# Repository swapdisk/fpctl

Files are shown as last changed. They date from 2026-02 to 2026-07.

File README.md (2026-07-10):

# fpctl: The FlightPath Controller

An ESP32-based physical cockpit designed to navigate the virtual skies of [FlightGear](https://www.flightgear.org/) and spark real-world conversations.

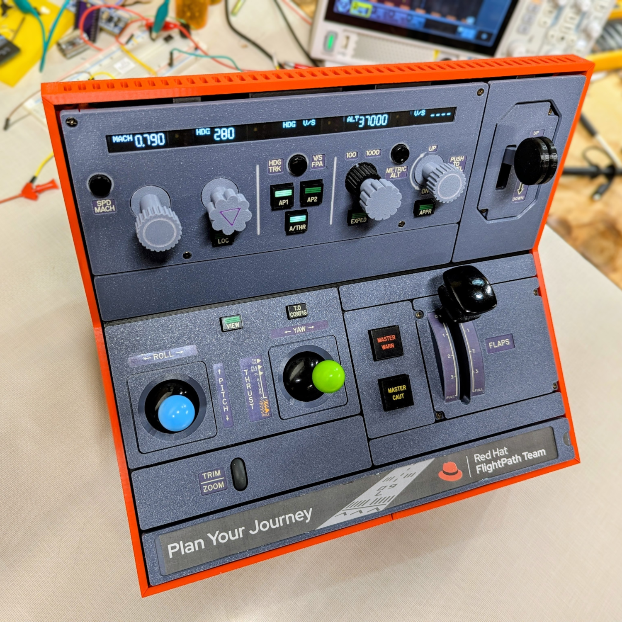
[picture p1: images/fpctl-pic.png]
FlightPath Controller


## About the Project

**fpctl** is a custom-built hardware flight deck interface designed specifically for the FlightPath Team at Red Hat.

Modeled largely after the Airbus A320 Flight Control Unit (FCU) and pedestal, this device serves as an interactive convention exhibit to show off on the expo floor and at happy hour receptions. Its primary purpose is to attract attention and serve as a unique conversation starter, demonstrating how physical hardware can integrate seamlessly with complex software systems, a tangible metaphor for the journeys we help our customers plan and execute.

It bridges the physical and digital worlds, allowing users to get hands-on with a flight simulator using realistic controls and displays, rather than just a keyboard and mouse.

## Features

The controller uses a hybrid approach to interface with the FlightGear simulator, combining low-latency USB HID inputs with bi-directional serial communication for complex data.

* The device appears to the host computer as both a standard USB HID Gamepad for sticks and buttons and a USB Serial device  for data exchange.
* The A320 FCU features dedicated rotary encoder knobs for speed/mach, heading/track, altitude, and vertical speed/FPA.
* Each knobs mechanically implements the push/pull functionality used to switch between manually-selected and FMGC-managed autopilot modes.
* Five distinct OLED screens provide real-time feedback from the simulator, showing current flight parameters like target altitude, heading and speed synced via a custom serial protocol.
* The physical controls include analog joysticks for flight control, joystick view mode for panning and zooming the main simulator canvas, a dedicated flaps lever with detents, a landing gear switch, and various autopilot engagement buttons.
* Visual and audio feedback features include master warning and caution indicators and a built-in speaker for clicks and alert sounds providing immediate sensory feedback.

## How It's Built

At its heart, the controller is powered by an ESP32 microcontroller. To manage the extensive array of inputs and outputs with limited pins, the project employs several engineering tricks:

* Multiplexing is used to update the five SSD1306 OLED displays which share the same I2C address. A [PCA9548A I2C switch](https://www.nxp.com/docs/en/data-sheet/PCA9548A.pdf) is used to rapidly switch between them, allowing individual updates.
* Input multiplexing is achieved using resistor ladders, allowing the dozens of buttons to be read using only three analog input pins, significantly reducing the total GPIO count required.
* Five high-precision rotary encoders manage the autopilot knobs with push/pull capability physically implemented with a custom 3D-printed "[floating hinge](FLIPPIES.md)" mechanism.
* Analog inputs use potentiometers handle the joysticks and the flaps lever position.

## Software Architecture

The ESP32 firmware is written in C++ using the Arduino framework. The main loop runs at around 30K iterations per second on an [Espressif ESP32-S3-DevKitC](https://docs.espressif.com/projects/esp-dev-kits/en/latest/esp32s3/esp-dev-kits-en-master-esp32s3.pdf), acting as a highly efficient manager of several distinct subsystems:

* Reads analog sticks and resistor ladder buttons, sending standard USB HID Gamepad events to the host PC.
* High-frequency polling of rotary encoders ensures precise input tracking without missed clicks.
* Bi-Directional serial sync:
  * Input: The ESP32 parses a custom, pipe-separated (`|`) data stream arriving from FlightGear via serial. This data drives the OLED displays and LED indicators, ensuring the hardware always matches the simulation state.
  * Output: Functions like changing autopilot targets and controlling simulator view/zoom are sent to FlightGear as nasal script commands to be executed by the simulator.

## What's Here

This repo contains all the files used to make this project, but no effort has been taken to make this something anybody can recreate exactly. What I made was very much a prototype engineered piece by piece without any final design plan. Here's a look inside:

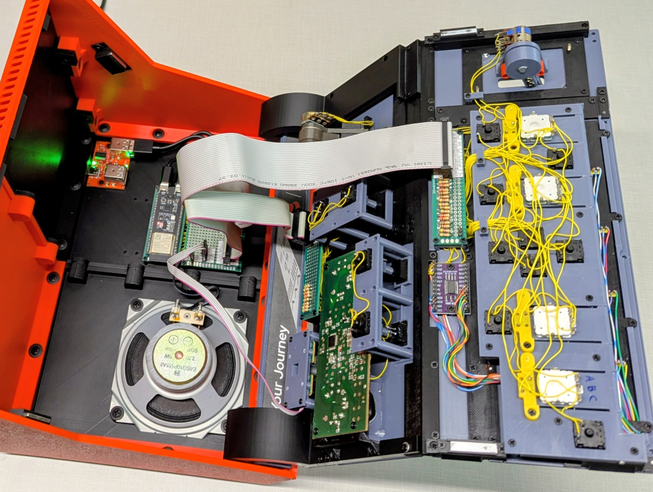
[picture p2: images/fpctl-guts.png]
Project Guts


There is no bill of materials listing everything you need to order up on Digikey. Many of the components came out of my parts bins or were scrapped from other projects. So it's in that vein what's in this repo is offered. It's not a recipe to recreate exactly what I built, but rather a collection of code and ideas you can draw on to create your own thing.

* The OpenSCAD files for all the 3D printed parts are under the [`3d`](./3d/) directory. I built this one panel at a time using a building block approach. With better planning and more discipline, it could have probably been done with half as many parts. Apologies in advance for the cryptic comments and plethora of magic numbers. Use what you can as you see fit.

* The ESP32 firmware is in [`src/fpctl.ino`](./src/fpctl.ino). Unlike the messy 3D models mentioned above, this is nice clean C++ code and commented pretty well.

Interfaces and modifications to FlightGear are implemented by the following files which must be copied as explained below.

* [`fgfs/Protocol/fpctl.xml`](./fgfs/Protocol/fpctl.xml) defines the serial protocol that sends data from FlightGear to the controller. This file needs to be copied to the `$FG_ROOT/Protocol` directory on the host. See the comments at the top of the file for the example option that needs to be given on the `fgfs` command line or configured in your `.fgfsrc` file.
* [`fgfs/Input/Joysticks/js0.xml`](./fgfs/Input/Joysticks/js0.xml) defines the input bindings for the USB HID Gamepad axes and buttons send from the controller. This file needs to be copied to your `$HOME/.fgfs/Input/Joysticks/` directory.
* [`bin/naselx.sh`](./bin/nasalx.sh) is a simple shell script that reads nasal script commands sent from the controller and forwards them to be executed by FlightGear. This script needs to be run in the background and FlightGear needs to be run with the following options on the `fgfs` command line or configured in your `.fgfsrc` file:<br>
`--telnet=5401`<br>
`--allow-nasal-from-sockets`
* [`fgfs/Liveries/FP-fuselage.png`](./fgfs/Liveries/FP-fuselage.png) is a 4k fuselage image I made for the FlightPath team. Copy this over the fuselage image file of the A320-family plane you are flying (e.g., `DLH-fuselage.png`) to see this rendered in the simulator.

## Credits

This project was made possible by the inspiration and contributions of many. Thank you!

* Josh Davidson, et al, for the very advanced [Airbus A320 Family](https://github.com/legoboyvdlp/A320-family) simulation for FlightGear
* Matthias Hertel's top notch [RotaryEncoder Arduino Library](https://github.com/mathertel/RotaryEncoder)
* Limor Fried and Adafruit Industries for their [Adafruit_SSD1306](https://github.com/adafruit/Adafruit_SSD1306/) OLED display library
* Chris Stone at Ignorant of Things for clearly explaining the right way to do [resistor ladders](https://ignorantofthings.com/pushing-adc-limits-with-the-perfect-multi-button-input-resistor-ladder/)
* Darren Embry's beautifully crafted [Routed Gothic Font](https://github.com/dse/routed-gothic)
* Red Hat for sharing their commercial-grade [typefaces](https://github.com/RedHatOfficial/RedHatFont) with open source licensing

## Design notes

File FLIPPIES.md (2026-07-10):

# FCU knobs push-pull implementation

Here a quick explanation of how we made the push-pull function for the FCU target knobs.

Each of the rotary encoders is mounted on floating hinge element of the base plate behind the FCU panel. These are referred to as "flippies" in the source code of [`fcu-p2.scad`](https://github.com/swapdisk/fpctl/blob/main/3d/fcu-p2.scad). For the hinge pin, we just used a piece 1.75 mm PLA filament. Sandwiched around each flippy are a pair of [`pushpull-fit.scad`](https://github.com/swapdisk/fpctl/blob/main/3d/pushpull-fit.scad) parts, one on top and one below. Each one holds a 6 mm tactile button switch in such a way to limit the movement of the encoder mounted to the flippy while activating either the top or bottom switch when the encoder knob is pushed and pulled.

The exploded view drawing and photo below should help you visualize how it's put together.

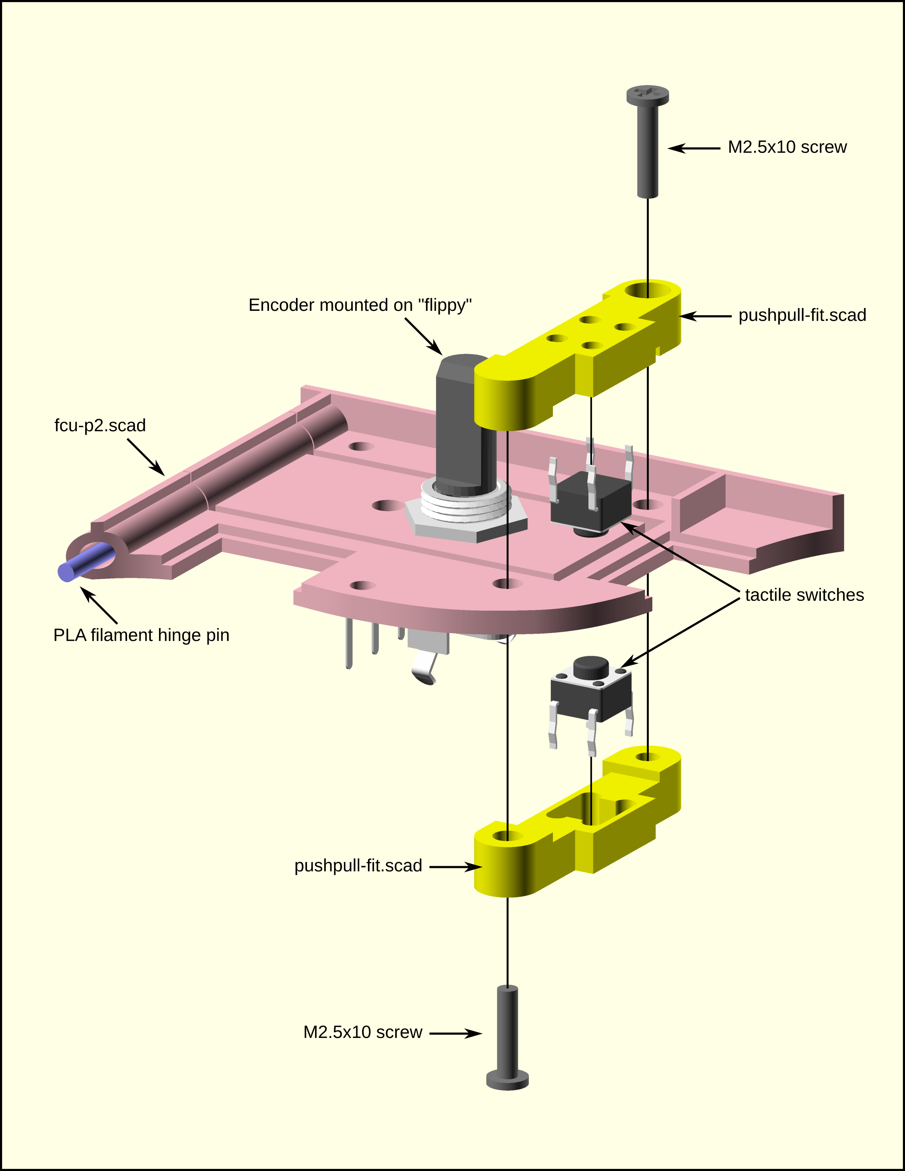
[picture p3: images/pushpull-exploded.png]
Exploded view of floating hinge mechanism


Photo of the assembled parts

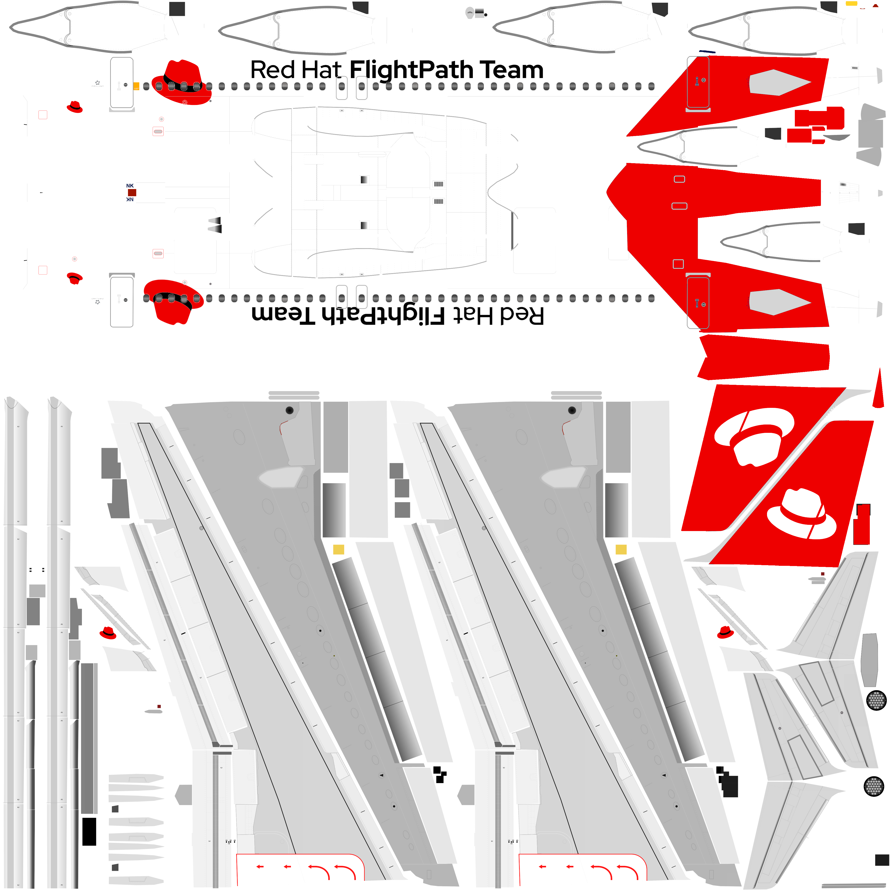
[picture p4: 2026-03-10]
fgfs/Liveries/FP-fuselage.png

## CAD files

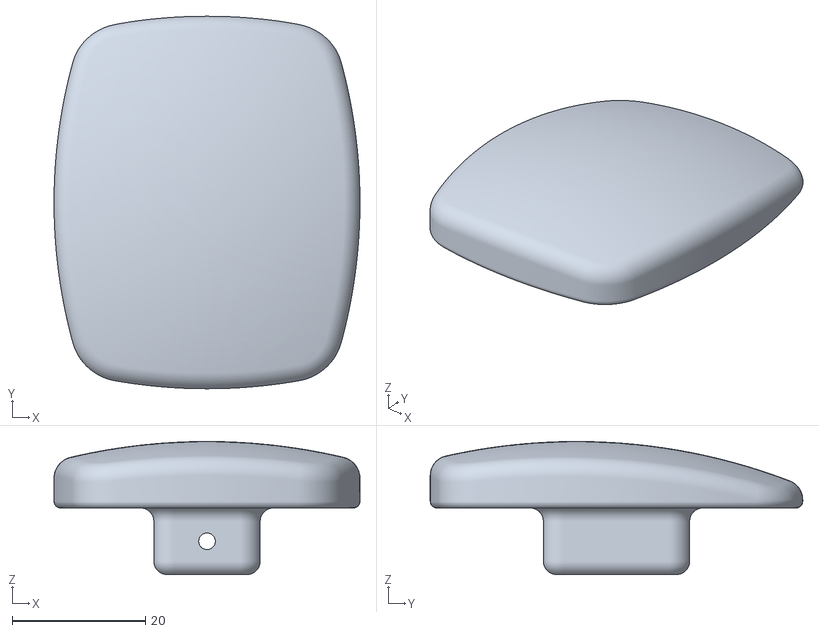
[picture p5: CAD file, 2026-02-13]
3d/flaps-assembly-ma60-21-top-knob.stl
46.0 x 56.0 x 20.0

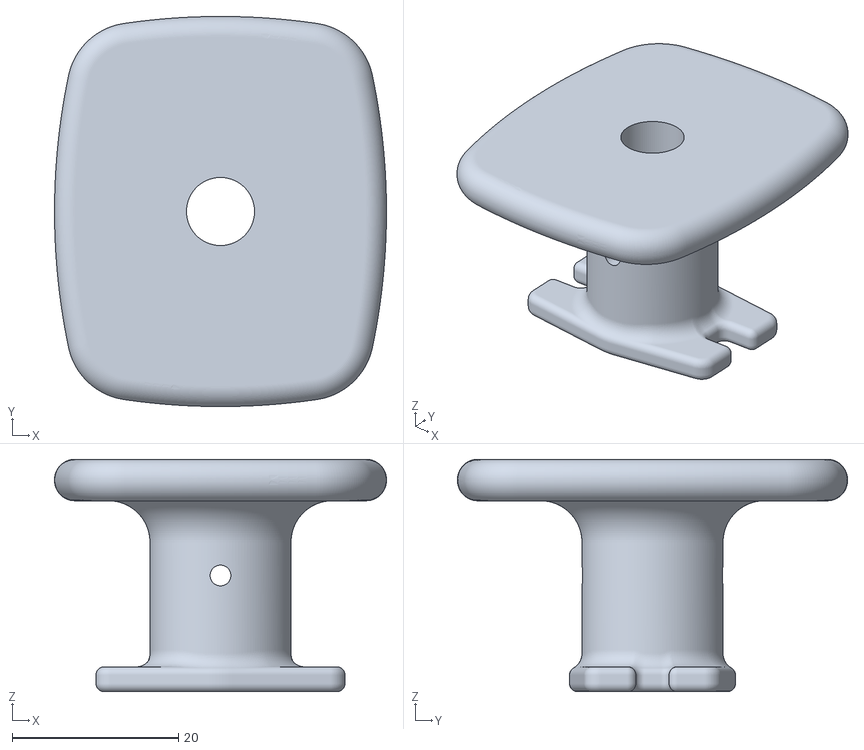
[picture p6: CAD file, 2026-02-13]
3d/flaps-assembly-ma60-20-pull-knob.stl
40.0 x 47.0 x 28.0

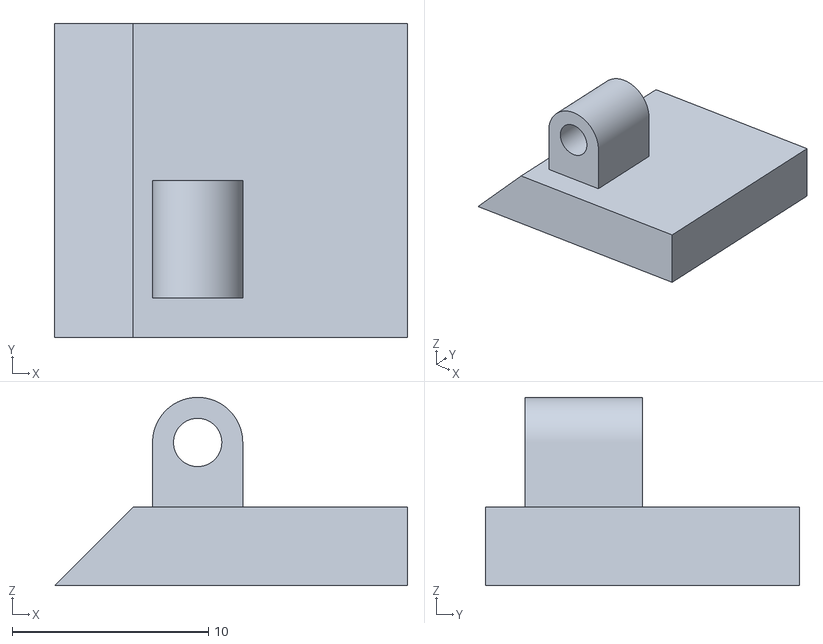
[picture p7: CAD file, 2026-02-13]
3d/case-corner-mini.stl
18.0 x 16.0 x 9.60

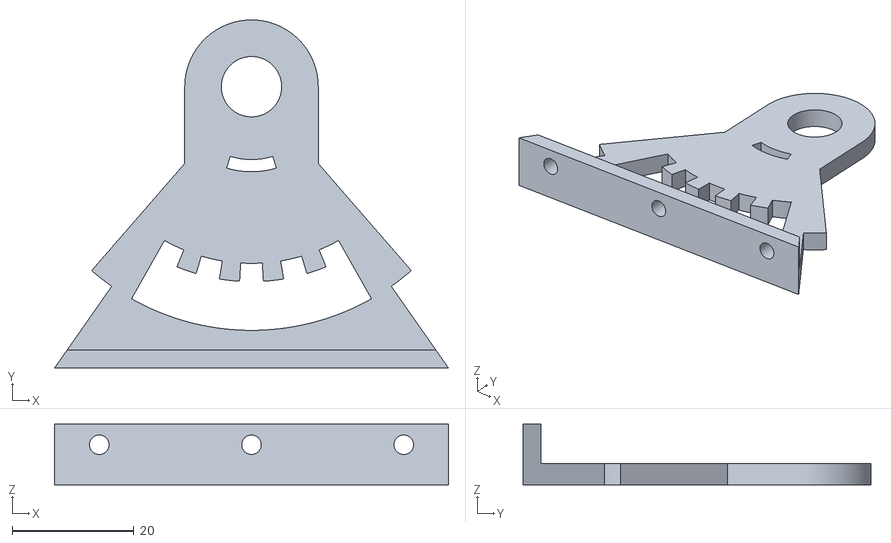
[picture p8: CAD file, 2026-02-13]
3d/flaps-control-lower.stl
64.7 x 57.1 x 10.0

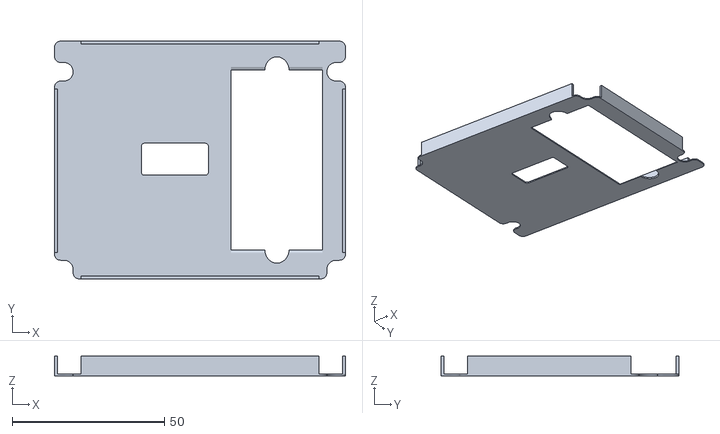
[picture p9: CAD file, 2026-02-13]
3d/flaps-control-face.stl
95.5 x 78.0 x 6.40

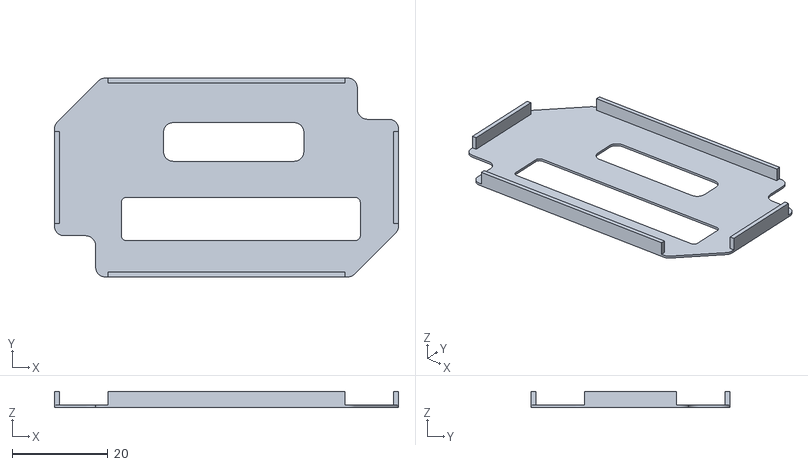
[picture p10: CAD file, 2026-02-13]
3d/gear-control-panel-face.stl
72.0 x 41.6 x 3.40

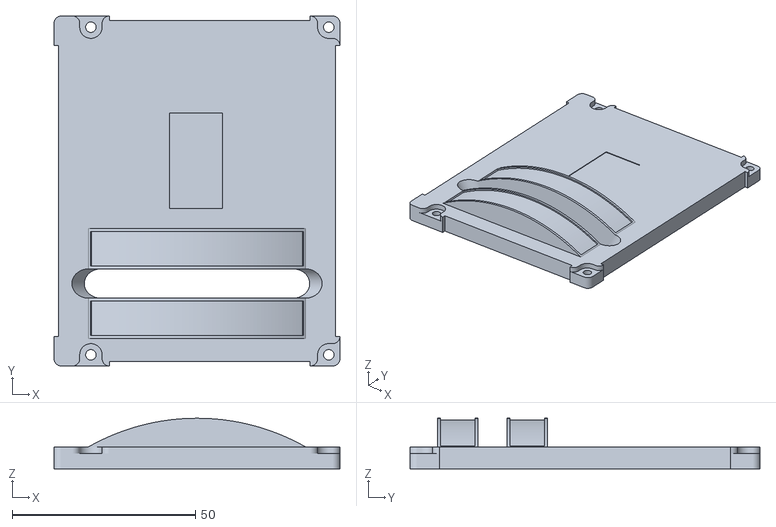
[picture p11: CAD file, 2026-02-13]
3d/flaps-control-panel.stl
78.0 x 95.5 x 13.8

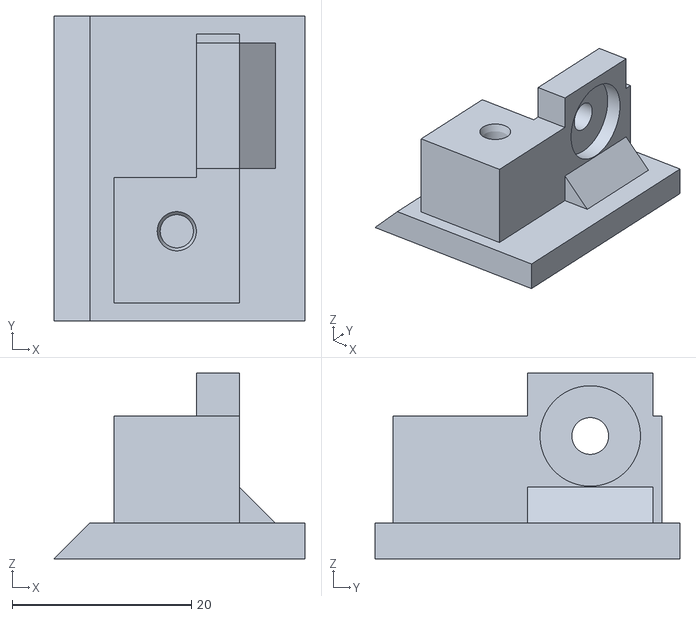
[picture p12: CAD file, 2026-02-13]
3d/case-corner-test.stl
28.0 x 34.0 x 20.7

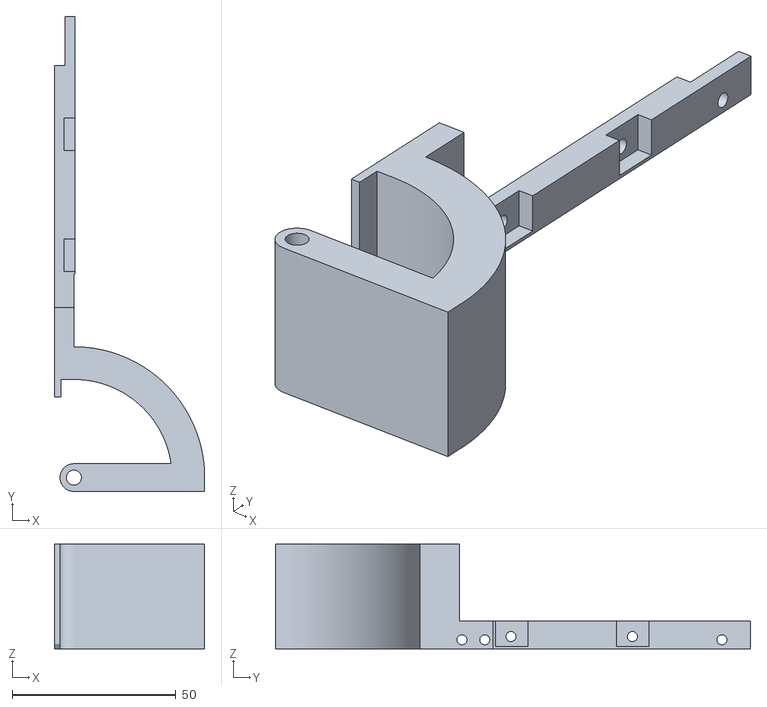
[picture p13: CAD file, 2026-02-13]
3d/hinge-left.stl
46.0 x 145.2 x 32.0

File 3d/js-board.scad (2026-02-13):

$fn=360;
eps=0.01;

// Board dims
pcb_x=115.10;
pcb_y=52.50;
pcb_thick=1.62;
pcb_hole_rad=2.64/2;
pcb_holes=[ [3.96, 4.08],
            [3.96, 41.22],
            [110.97, 4.08],
            [110.97, 41.22]];
            
// Joystick control dims
jsc_x=15.75;
jsc_y=15.75;
jsc_z=12.22;
jsc_pos=[ [9.40, 13.45],
          [89.56, 13.45]];
          
// Stick dims
jss_x=1.86;
jss_y=1.18;
jss_z=19.62;

// Dome position
dome_high=10.75;

// Debug show board, etc.
translate([0, 0, -pcb_thick]) difference() {
    union() {
        // base pcb
        color("powderblue") cube([pcb_x, pcb_y, pcb_thick]);
        // Joysticks
        color("silver") for (j=jsc_pos) {
            translate([j[0], j[1], pcb_thick])
                cube([jsc_x, jsc_y, jsc_z]);
            translate([j[0]+jsc_x/2-jss_x/2, j[1]+jsc_y/2-jss_y/2, pcb_thick])
                cube([jss_x, jss_y, jss_z]);
        }
        // Domes
        color("grey") for (j=jsc_pos) {
            translate([j[0]+jsc_x/2, j[1]+jsc_y/2, pcb_thick+dome_high]) {
                include <ex-sphere.scad>;
            }
        }
    }
    for (h=pcb_holes) {
        translate([h[0], h[1], -eps]) cylinder(99, pcb_hole_rad, pcb_hole_rad);
    }
}

// Shorten brackets to go under jointer by this amount
shorter=2.3;

// Bracket poly points
bpp=[[0, shorter],
     [0, 5],
     [5.5, 10.5],
     [5.5, 18.82],
     [17.5-7.5/2, 18.82],
     [17.5-7.5/2, 18.82-2.10],
     [9.58+2.10, 18.82-2.10],
     [7.5, 12.12],
     [7.5, shorter]];
pcb_screw_rad=2.46/2;
pcb_screw_deep=2.7;
pan_hole_rad=3.06/2;
pan_head_rad=4.60/2;
pan_deep=5.5;

//            [3.96, 41.22],
//            [110.97, 4.08],
//            [110.97, 41.22]];
// right bracket
translate([110.97+3.96, 0.21+41.22+3.88, 0]) rotate([0, 0, 180]) difference() {
    translate([-9.75, 0.21, 18.82]) {
        // body
        rotate([90, 180, 180]) linear_extrude(7.5) polygon(bpp);
        translate([0, 41.22-4.08, 0]) rotate([90, 180, 180]) {
            linear_extrude(7.5) polygon(bpp);
        }
        translate([17.5-7.5/2, 7.5/2, -18.82]) rotate([0, 0, 0]) cylinder(2.10, 7.5/2, 7.5/2);
        translate([17.5-7.5/2, 41.22-4.08+7.5/2, -18.82]) rotate([0, 0, 0]) cylinder(2.10, 7.5/2, 7.5/2);
        translate([5.5, 0, -18.82]) cube([2, 41.22, 18.82-8.5]);
    }
    // board screw holes
    for (h=[[3.96, 4.08], [3.96, 41.22]]) {
        translate([h[0], h[1], -eps]) cylinder(pcb_screw_deep, pcb_screw_rad, pcb_screw_rad);
    }
    // panel screw holes
    for (h=[[-7, 4.08], [-7, 41.22]]) {
        translate([h[0], h[1], -eps]) cylinder(99, pan_hole_rad, pan_hole_rad);
        translate([h[0], h[1], -eps]) cylinder(18.82-pan_deep, pan_head_rad, pan_head_rad);
    }
}

// left bracket
difference() {
    translate([-9.75, 0.21, 18.82]) {
        // body
        rotate([90, 180, 180]) linear_extrude(7.5) polygon(bpp);
        translate([0, 41.22-4.08, 0]) rotate([90, 180, 180]) linear_extrude(7.5) polygon(bpp);
        translate([17.5-7.5/2, 7.5/2, -18.82]) rotate([0, 0, 0]) cylinder(2.10, 7.5/2, 7.5/2);
        translate([17.5-7.5/2, 41.22-4.08+7.5/2, -18.82]) rotate([0, 0, 0]) cylinder(2.10, 7.5/2, 7.5/2);
        translate([5.5, 0, -18.82]) cube([2, 41.22, 18.82-8.5]);
    }
    // board screw holes
    for (h=[[3.96, 4.08], [3.96, 41.22]]) {
        translate([h[0], h[1], -eps]) cylinder(pcb_screw_deep, pcb_screw_rad, pcb_screw_rad);
    }
    // panel screw holes
    for (h=[[-7, 4.08], [-7, 41.22]]) {
        translate([h[0], h[1], -eps]) cylinder(99, pan_hole_rad, pan_hole_rad);
        translate([h[0], h[1], -eps]) cylinder(18.82-pan_deep, pan_head_rad, pan_head_rad);
    }
}

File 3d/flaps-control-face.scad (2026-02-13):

$fn=360;
eps=0.01;

// Cover dims
cov_thick=0.50;

// Minifactorize
mf=20;

// Bezel dims
bezel_thick=3;
bezel_corner_rad=3;
bezel_f=1.25;

// Panel dims
panel_thick=3;
panel_margin=6;
panel_f=1.3;
panel_l=7.5;
panel_r=58;

// Flap control dims
arch_rad=80-mf;
total_wide=30;
slot_wide=8;
detent_wide=8;
detent_rad=arch_rad-28;
detent_deep=3;
detent_deg=7;

// Deco mounting corners
dmc_xy=6.10;
dmc_ty=7.00;
sm_rad=2;
lg_rad=dmc_xy/2;
dmc_hole_rad=2.86/2;
gp_base=4.2;
gp_high=arch_rad*panel_f;
gp_wide=panel_l+total_wide+panel_r;

// Potentiometer dims
pot_rad=9.90/2;
pot_reg_wide=2.0;
pot_reg_offset=11.96;

// Label cavity
lc_deep=0.5;
lc_edge=0.8;

// Label
lab_thick=0.20;
lab_rad=1;
lab_mar=3;
lab_corners=[[-36, 45, lab_rad],
            [-36-8.5, 45, lab_rad],
            [-36-8.5, 45+20, lab_rad],
            [-36, 45+20, lab_rad]];

// Attachment
screw_rad=2.46/2;
screw_deep=panel_thick+bezel_thick+2;
el_thick=3;
el_holes_rad=3.20/2;

// Face tabs
s=1.10;
tab_thick=1.0;
ft=[[dmc_xy*2+dmc_ty+sm_rad-gp_high+s/2, 0, gp_high-dmc_xy*2-sm_rad*2-dmc_ty-s, tab_thick],
    [dmc_xy*2+dmc_ty+sm_rad-gp_high+s/2, gp_wide-tab_thick, gp_high-dmc_xy*2-sm_rad*2-dmc_ty-s, tab_thick],
    [dmc_xy-tab_thick, dmc_xy+sm_rad+s/2, tab_thick, gp_wide-sm_rad*2-dmc_xy*2-s],
    [dmc_xy-gp_high, dmc_xy+sm_rad+s/2, tab_thick, gp_wide-sm_rad*2-dmc_xy*2-s]];

// subtractable radius
module sr(deg) {
    rotate([0, 0, deg]) linear_extrude(99) {
        difference() {
            square([sm_rad, sm_rad]);
            intersection() {
                square([sm_rad, sm_rad]);
                translate([sm_rad, sm_rad, 0]) circle(sm_rad);
            }
        }
    }
}

rotate([0, 180, 90]) translate([0, 0, -arch_rad*0.87+panel_thick+bezel_thick]) difference() {
    union() {
        // face tabs
        translate([arch_rad*panel_f/2-dmc_xy,
                       -total_wide-panel_l, 
                       arch_rad*0.87-cov_thick]) {
            for (f=ft) {
                translate([f[0], f[1], -6+0.1]) cube([f[2], f[3], 6]);
            }
        }
    }
}

//projection(cut=true) translate([0, 0, panel_thick+bezel_thick])
rotate([0, 180, 90]) translate([0, 0, -arch_rad*0.87+panel_thick+bezel_thick]) difference() {
    union() {
        // guide base
        rotate([90, -49, 0]) rotate_extrude(angle=82) 
            translate([0, 0, 0]) square([detent_rad+detent_wide, total_wide]);
        
        // panel 
        translate([-arch_rad*panel_f/2,
                   -total_wide-panel_l, 
                   arch_rad*0.87-panel_thick-bezel_thick])
            linear_extrude(bezel_thick+panel_thick) hull() {
                translate([sm_rad, sm_rad, 0]) circle(sm_rad);
                translate([arch_rad*panel_f-sm_rad, sm_rad, 0]) circle(sm_rad);
                translate([arch_rad*panel_f-sm_rad, panel_l+total_wide+panel_r-sm_rad, 0])
                    circle(sm_rad);
                translate([sm_rad, panel_l+total_wide+panel_r-sm_rad, 0]) circle(sm_rad);    
        }
    }

    // Cover only
    translate([-49, -49, arch_rad*0.87-99-cov_thick]) cube([99, 99*2, 99]);
    
    // main control body
    rotate([90, -55, 0]) rotate_extrude(angle=70) square([arch_rad, total_wide]);

    
    // subtract face tabs
//    translate([arch_rad*panel_f/2-dmc_xy,
//                   -total_wide-panel_l, 
//                   arch_rad*0.87-panel_thick-bezel_thick]) {
//        for (f=ft) {
//            translate([f[0], f[1], -eps]) cube([f[2], f[3], 99]);
//        }
//    }

    // subtract deco mounting corners
    // bottom left
    translate([arch_rad*panel_f/2-dmc_xy,
                   -total_wide-panel_l, 
                   arch_rad*0.87-panel_thick-bezel_thick]) {
                   //%cylinder(99, .1, .1);
        translate([0, 0, gp_base]) sr(90);
        translate([dmc_xy, dmc_xy, gp_base]) sr(90);
        translate([0, 0, gp_base]) linear_extrude(9) hull() {
            translate([dmc_xy, dmc_xy-lg_rad, 0]) circle(lg_rad);
            translate([lg_rad, dmc_xy-lg_rad, 0]) circle(lg_rad);
            translate([lg_rad, 0, 0]) circle(lg_rad);
            translate([dmc_xy, 0, 0]) circle(lg_rad);
        }
        translate([dmc_xy-lg_rad, dmc_xy-lg_rad, -eps])
            cylinder(99, dmc_hole_rad, dmc_hole_rad);
    }
    // bottom right
    translate([arch_rad*panel_f/2-dmc_xy,
                   -total_wide-panel_l, 
                   arch_rad*0.87-panel_thick-bezel_thick]) {
        translate([0, panel_l+total_wide+panel_r, gp_base]) sr(180);
        translate([dmc_xy, panel_l+total_wide+panel_r-dmc_xy, gp_base]) sr(180);
        translate([0, panel_l+total_wide+panel_r-dmc_xy/2, gp_base]) linear_extrude(9) hull() {
            translate([dmc_xy, dmc_xy-lg_rad, 0]) circle(lg_rad);
            translate([lg_rad, dmc_xy-lg_rad, 0]) circle(lg_rad);
            translate([lg_rad, 0, 0]) circle(lg_rad);
            translate([dmc_xy, 0, 0]) circle(lg_rad);
        }
        translate([dmc_xy-lg_rad, panel_l+total_wide+panel_r-lg_rad, -eps]) 
            cylinder(99, dmc_hole_rad, dmc_hole_rad);
    }
    // top left
    translate([dmc_ty-arch_rad*panel_f/2,
                   -total_wide-panel_l, 
                   arch_rad*0.87-panel_thick-bezel_thick]) {
        translate([0, 0, gp_base]) sr(90);
        translate([dmc_xy, 0, gp_base]) sr(0);
        translate([0, 0, gp_base]) linear_extrude(9) hull() {
            translate([lg_rad, dmc_xy-lg_rad, 0]) circle(lg_rad);
            translate([lg_rad, 0, 0]) circle(lg_rad);
        }
        translate([lg_rad, dmc_xy-lg_rad, -eps]) 
            cylinder(99, dmc_hole_rad, dmc_hole_rad);
    }
    // top right
    translate([dmc_ty-arch_rad*panel_f/2,
                   -total_wide-panel_l, 
                   arch_rad*0.87-panel_thick-bezel_thick]) {
        translate([0, panel_l+total_wide+panel_r, gp_base]) sr(180);
        translate([dmc_xy, panel_l+total_wide+panel_r, gp_base]) sr(270);
        translate([0, panel_l+total_wide+panel_r-dmc_xy/2, gp_base]) linear_extrude(9) hull() {
            translate([lg_rad, dmc_xy-lg_rad, 0]) circle(lg_rad);
            translate([lg_rad, 0, 0]) circle(lg_rad);
        }
        translate([lg_rad, panel_l+total_wide+panel_r-lg_rad, -eps]) 
            cylinder(99, dmc_hole_rad, dmc_hole_rad);
    }

    translate([0, -total_wide/2+slot_wide/2, 0]) {
        // lever slot
        rotate([90, -60.5, 0]) rotate_extrude(angle=59) square([999, slot_wide]);
        // round ends of slot
        translate([0, -slot_wide/2, 0])
            rotate([-29.5, 0, 90]) cylinder(999, slot_wide/2, slot_wide/2);
        translate([0, -slot_wide/2, 0])
            rotate([29.5, 0, 90]) cylinder(999, slot_wide/2, slot_wide/2);
        // subtract left side
        translate([-arch_rad*panel_f/2, -total_wide+1, -999])
            cube([arch_rad*panel_f, total_wide, 999+arch_rad*0.87-panel_thick-bezel_thick]);
        // subtract right side
        translate([-arch_rad*panel_f/2, 3.5-3+slot_wide/2, -999])
            cube([arch_rad*panel_f, total_wide, 
                999+arch_rad*0.87-panel_thick-bezel_thick-el_thick]);
    }
    // el holes
    for (x = [-arch_rad*bezel_f/3, 0, arch_rad*bezel_f/3]) {
        translate([x, -4.4-3+slot_wide/2, arch_rad*0.87-panel_thick-bezel_thick-el_thick-eps]) 
            cylinder(el_thick+eps+eps, el_holes_rad, el_holes_rad);
    }
    // screw holes
    for (x = [-arch_rad*bezel_f/3, 0, arch_rad*bezel_f/3]) {
        translate([x, -4.4-3+slot_wide/2, arch_rad*0.87-panel_thick-bezel_thick-eps]) 
            cylinder(screw_deep-0.9, screw_rad, screw_rad);
        translate([x, 4.4+3-slot_wide/2-total_wide, arch_rad*0.87-panel_thick-bezel_thick-eps]) 
            cylinder(screw_deep-0.9, screw_rad, screw_rad);
    }

    // label cavities
    rotate([90, -61, 0]) rotate_extrude(angle=58) 
        translate([arch_rad-lc_deep, lc_edge, 0])
            square([999, total_wide/2-slot_wide/2-lc_edge*2]);
    rotate([90, -61, 0]) rotate_extrude(angle=58) 
        translate([arch_rad-lc_deep, lc_edge+total_wide/2+slot_wide/2, 0])
            square([999, total_wide/2-slot_wide/2-lc_edge*2]);

    // subtract label
    translate([arch_rad*panel_f/2,
                   -total_wide-panel_l, 
                   0]) linear_extrude(99) hull() {
        for (i = [0:3]) {
            c=lab_corners[i];
            translate([c[0]+c[2],
                       c[1]+c[2],
                       0]) circle(lab_rad);
        }
    }
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

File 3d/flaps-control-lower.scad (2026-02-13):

eps=0.01;

rotate([90, 0, 0]) difference() {
    union() {
        include<flaps-control.scad>;
    }
    translate([0, 0, -eps]) cylinder(99, 99, 99);
}

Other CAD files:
3d/flaps-control-mockup.scad
3d/alt-units-knob-flange.scad
3d/alt-units-knob-pointer.scad
3d/alt-units-knob-ring.scad
3d/alt-units-proto.scad
3d/blank-panel-a.scad
3d/blank-panel-b-face.scad
3d/blank-panel-b.scad
3d/c2-keymate.scad
3d/case-back-left.scad
3d/case-back-right.scad
3d/case-bottom-left.scad
3d/case-bottom-right.scad
3d/case-bottom.scad
3d/case-corner-mini.scad
3d/case-corner-test.scad
3d/case-esp-adapter.scad
3d/case-front-panel-left.scad
3d/case-front-panel-right.scad
3d/case-side-left-panel.scad
3d/case-side-right-panel.scad
3d/case-top-stop.scad
3d/case-top.scad
3d/cherry-cherry-short.scad
3d/cherry-cherry.scad
3d/cherry-escutcheon.scad
3d/cherry-female.scad
3d/cherry-keycap-fcu0.scad
3d/cherry-keycap-fcu1.scad
3d/cherry-keycap-fcu2.scad
3d/cherry-keymate.scad
3d/cherry-ko.scad
3d/disp-clip.scad
3d/duct-cover-raceway.scad
3d/ex-sphere.scad
3d/fcu-display.scad
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

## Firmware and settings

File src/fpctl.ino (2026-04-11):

/*
  fpctl

  Interface Airbus A320 cockpit to FlightGear flight sim using ESP32.

  The controller appears on the USB bus as both a HID gamepad device and 
  a serial port. Most of the inputs to FlightGear are handled as joystick 
  axes and buttons. The other inputs are implemented by sending nasal 
  commands over the serial port. We also read from the serial port to get 
  outputs from a custom FlightGear protocol to update the FCU displays 
  and indicators.

  https://github.com/swapdisk/fpctl
  
  (c) 2026 Bob Mader
  MIT License

*/

// USB and Gamepad libraries
#include "USB.h"
#include "USBHIDGamepad.h"
USBHIDGamepad gp;

// OLED libraries
#include <SPI.h>
#include <Wire.h>
#include <Adafruit_GFX.h>
#include <Adafruit_SSD1306.h>

// SSD1306 I2C pins and settings
#define SCREEN_SDA 1
#define SCREEN_SCL 2
#define OLED_RESET -1
#define SCREEN_WIDTH 128
#define SCREEN_HEIGHT 32
#define SCREEN_ADDR 0x3C  // OLED displays all at the same address
#define SWITCH_ADDR 0x70  // PCA9548A I2C switch address
Adafruit_SSD1306 display(SCREEN_WIDTH, SCREEN_HEIGHT, &Wire, OLED_RESET);

// Pins for stateful switches
#define PIN_GEAR 3
#define PIN_UNITS 0  // Sadly, this is also the boot pin

// Multi-button resistor ladder magic
// https://ignorantofthings.com/pushing-adc-limits-with-the-perfect-multi-button-input-resistor-ladder/
#define BUTTONS 8
#define RESOLUTION 4095
#define PIN_RL1 4
#define PIN_RL2 8
#define PIN_RL3 6

// Potentiometer input pins
#define PIN_JS0X 7
#define PIN_JS0Y 15
#define PIN_JS1X 16
#define PIN_JS1Y 17
#define PIN_FLAPS 18

// LED indicator output pins
#define PIN_LOC 46
#define PIN_ATHR 9
#define PIN_AP1 10
#define PIN_AP2 11
#define PIN_EXPED 12
#define PIN_APPR 13
#define PIN_VIEW 14
#define PIN_WARN 48
#define PIN_CAUT 47

// Speaker output pin
#define PIN_SPEAKER 38

// Encoder pin assignments
#define PIN_ENC1A 42
#define PIN_ENC1B 41
#define PIN_ENC2A 40
#define PIN_ENC2B 39
#define PIN_ENC3A 21
#define PIN_ENC3B 37
#define PIN_ENC4A 36
#define PIN_ENC4B 35
#define PIN_ENC5A 5
#define PIN_ENC5B 45

// Setup encoders
// https://github.com/mathertel/RotaryEncoder
// LatchMode::FOUR3 is 4 steps per latch or 24 steps per turn
// LatchMode::TWO03 is 2 steps per latch or 48 steps per turn
#include <RotaryEncoder.h>
RotaryEncoder encoderSPD(PIN_ENC1A, PIN_ENC1B, RotaryEncoder::LatchMode::FOUR3);
RotaryEncoder encoderHDG(PIN_ENC2A, PIN_ENC2B, RotaryEncoder::LatchMode::FOUR3);
RotaryEncoder encoderALT(PIN_ENC3A, PIN_ENC3B, RotaryEncoder::LatchMode::FOUR3);
RotaryEncoder encoderVS(PIN_ENC4A, PIN_ENC4B, RotaryEncoder::LatchMode::FOUR3);
RotaryEncoder encoderTrim(PIN_ENC5A, PIN_ENC5B, RotaryEncoder::LatchMode::TWO03);

// Magic encoder values to force display update while not sending nasal command
const int dontSendSPD = 0;
const int dontSendHDG = 0;
const int dontSendALT = 0;
const int dontSendVS = 999;

// Set encoder position default values
int encoderSPDPos = 100;
int encoderHDGPos = 360;
int encoderALTPos = 100;
int encoderVSPos = 0;
int encoderTrimPos = 0;

// Serial read buffer
const int maxBuffer = 128;
char serialBuffer[maxBuffer];
int bufferIndex = 0;

// Loop counter and timers
unsigned long loopCount = 0;
unsigned long loopDiff = 0;
unsigned long currentTime = 0;
unsigned long lastAct = 0;
unsigned long prevTime = 0;

// Display timeout values
unsigned long dispDimMillis = 300000;   // 5 minutes
unsigned long dispOffMillis = 1200000;  // 20 minutes

// Potentiometer read timer
const int potMillis = 100;
unsigned long whenPot = 0;

// Rolling average configuration for view mode damping
// Number of samples in moving average (higher is smoother, but laggier)
const int VIEW_AVG_WINDOW = 4;
// Additional damping 0.0-0.9 (higher for more damping)
const float VIEW_DAMPING_FACTOR = 0.8;

// Rolling average buffers for view mode joystick
int viewAxisXBuffer[VIEW_AVG_WINDOW] = {0};
int viewAxisYBuffer[VIEW_AVG_WINDOW] = {0};
int viewBufferIndex = 0;
int smoothedViewX = 0;
int smoothedViewY = 0;

// Stateful switch vars
int oldGear = -1;
int oldUnits = -1;

// Flaps position
int oldFlapsPos = -1;

// FCU modes
bool ktsMachMode = false;
bool trkFpaMode = false;
bool unitsMode = false;
bool spdDashes = false;
bool spdDot = false;
bool hdgDashes = false;
bool hdgDot = false;
bool vsDashes = true;
bool vsDot = false;
bool warnBlink = false;

// Internal modes
bool debugMode = false;
bool viewMode = false;
unsigned long lastViewPress = 0;

// Resistor ladder vars
// old* used for detecting button change
int oldRL1 = -1;
int oldRL2 = -1;
int oldRL3 = -1;
// prev* used for debounce and button release
int prevRL1 = 0;
int prevRL2 = 0;
int prevRL3 = 0;

// Debounce timer vars
unsigned long whenRL1 = 0;
unsigned long whenRL2 = 0;
unsigned long whenRL3 = 0;
const unsigned long bounceWait = 50;

// Mapping of RL buttons to HID gamepad buttons
const int buttonMap[24] = {
  24,  // R1-1 SPD pull
  25,  // R1-2 HDG pull
  26,  // R1-3 ALT pull
  27,  // R1-4 VS pull
  28,  // R1-5 SPD push
  29,  // R1-6 HDG push
  30,  // R1-7 ALT push
  31,  // R1-8 VS push
  12,  // R2-1 A/THR
  13,  // R2-2 LOC
  14,  // R2-3 SPD/MACH
  15,  // R2-4 AP1
  16,  // R2-5 AP2
  17,  // R2-6 HDG/TRK
  18,  // R2-7 EXPED
  19,  // R2-8 APPR
  20,  // R3-1 METRIC
  21,  // R3-2 MAST WARN
  22,  // R3-3 MAST CAUT
  -1,  // R3-4 VIEW (not sent)
  23,  // R3-5 TO CONFIG
  -1,  // R3-6 TRIM (not sent)
  -1,  // R3-7 JS0 (not sent)
  -1   // R3-8 JS1 (not sent)
};

// Switch PCA9548A channel to select OLED
void selectOLED(uint8_t i) {
  if (i > 7) return;
  Wire.beginTransmission(SWITCH_ADDR);
  Wire.write(1 << i);
  Wire.endTransmission();
}

// Read joystick and return axis value
int scaleAxis(uint8_t pin) {
  int reading = analogRead(pin);

  // Convert 12-bit ADC to 8-bit HID gamepad axis
  return (reading / 16) - 128;
}

// Apply rolling average with damping for smooth view panning
int smoothViewAxis(int* buffer, int newValue, int* smoothed) {
  // Add new value to circular buffer
  buffer[viewBufferIndex] = newValue;

  // Calculate simple moving average
  int sum = 0;
  for (int i = 0; i < VIEW_AVG_WINDOW; i++) {
    sum += buffer[i];
  }
  int avg = sum / VIEW_AVG_WINDOW;

  // Apply exponential smoothing for additional damping
  *smoothed = (int)(avg * (1.0 - VIEW_DAMPING_FACTOR) + *smoothed * VIEW_DAMPING_FACTOR);

  return *smoothed;
}

// Flaps potentiometer magic numbers
const int flapsMagic[] = { 3600, 3000, 2500, 2050 };
const int maxFlapsPos = 4;

// Read flaps control and return flaps setting
int getFlapsPos(uint8_t pin) {
  int reading = analogRead(pin);

  // Loop through flaps detents
  for (int i = 0; i < maxFlapsPos; i++) {
    if (reading > flapsMagic[i]) {
      return i;
    }
  }

  // Else, we are at full flaps
  return maxFlapsPos;
}

// Read resistor ladder pin and return button index
int getButton(uint8_t pin) {
  int reading = analogRead(pin);
  float stepSize = RESOLUTION / (float)BUTTONS;

  // Use rounding to calculate button index
  int buttonIndex = (int)((reading + (stepSize / 2.0)) / stepSize) + 1;

  // Index higher than our button count means no button pressed
  if (buttonIndex > BUTTONS) return 0;

  return buttonIndex;
}

// Sound for encoder steps
void click() {
  tone(PIN_SPEAKER, 1800, 4);
}

// Sound for button press
void boop() {
  tone(PIN_SPEAKER, 144, 24);
}

// Seven-segment digit mapping
//   +-a-+
//   f   b
//   +-g-+
//   e   c
//   +-d-+
const int segmentMap[13][8] = {
  // a, b, c, d, e, f, g, +
  { 1, 1, 1, 1, 1, 1, 0, 0 },  // 0
  { 0, 1, 1, 0, 0, 0, 0, 0 },  // 1
  { 1, 1, 0, 1, 1, 0, 1, 0 },  // 2
  { 1, 1, 1, 1, 0, 0, 1, 0 },  // 3
  { 0, 1, 1, 0, 0, 1, 1, 0 },  // 4
  { 1, 0, 1, 1, 0, 1, 1, 0 },  // 5
  { 1, 0, 1, 1, 1, 1, 1, 0 },  // 6
  { 1, 1, 1, 0, 0, 0, 0, 0 },  // 7
  { 1, 1, 1, 1, 1, 1, 1, 0 },  // 8
  { 1, 1, 1, 1, 0, 1, 1, 0 },  // 9
  { 0, 0, 0, 0, 0, 0, 1, 0 },  // - (10)
  { 0, 0, 0, 0, 0, 0, 1, 1 },  // + (11)
  { 0, 0, 1, 1, 1, 0, 1, 0 }   // o (12)
};

// Write up to 3-digit number
void writeDigits(Adafruit_SSD1306 &d, uint8_t xCursor, uint8_t yCursor, uint8_t space, int digit, uint8_t color, bool showZero) {
  digit = abs(digit);
  int segmentMap[] = { digit / 100 % 10, digit / 10 % 10, digit % 10 };
  if (digit > 99 || showZero) {
    writeDigit(d, xCursor, yCursor, segmentMap[0], color);
  }
  if (digit > 9 || showZero) {
    writeDigit(d, xCursor + space, yCursor, segmentMap[1], color);
  }
  writeDigit(d, xCursor + (space * 2), yCursor, segmentMap[2], color);
}

// Write one digit
void writeDigit(Adafruit_SSD1306 &d, uint8_t xCursor, uint8_t yCursor, int digit, uint8_t color) {
  for (uint8_t i = 0; i < 8; i++) {
    bool seg = segmentMap[digit][i];
    // if seg_on is true draw segment
    if (seg) {
      switch (i) {
        case 0:
          d.fillRoundRect(2 + xCursor, 0 + yCursor, 11, 3, 2, color);  // a
          break;
        case 1:
          d.fillRoundRect(12 + xCursor, 2 + yCursor, 3, 12, 2, color);  // b
          break;
        case 2:
          d.fillRoundRect(12 + xCursor, 14 + yCursor, 3, 12, 2, color);  // c
          break;
        case 3:
          d.fillRoundRect(2 + xCursor, 26 + yCursor, 11, 3, 2, color);  // d
          break;
        case 4:
          d.fillRoundRect(0 + xCursor, 14 + yCursor, 3, 12, 2, color);  // e
          break;
        case 5:
          d.fillRoundRect(0 + xCursor, 2 + yCursor, 3, 12, 2, color);  // f
          break;
        case 6:
          d.fillRoundRect(2 + xCursor, 13 + yCursor, 11, 3, 2, color);  // g
          break;
        case 7:
          d.fillRoundRect(6 + xCursor, 6 + yCursor, 3, 6, 2, color);   // plus top
          d.fillRoundRect(6 + xCursor, 17 + yCursor, 3, 6, 2, color);  // plus bottom
          break;
      }
      seg = false;
    }
  }
}

// Run initial setup
void setup() {
  // Set up serial port
  Serial.begin(115200);
  while (! Serial) delay(10);
  Serial.printf("\n");
  Serial.printf("Starting setup. (%d)\n", millis());

  // Set up input for stateful switches
  pinMode(PIN_GEAR, INPUT_PULLUP);
  pinMode(PIN_UNITS, INPUT_PULLUP);

  // Set up input pins for resistor ladders
  pinMode(PIN_RL1, INPUT);
  pinMode(PIN_RL2, INPUT);
  pinMode(PIN_RL3, INPUT);

  // Set up input pins for other A/D inputs
  pinMode(PIN_JS0X, INPUT);
  pinMode(PIN_JS0Y, INPUT);
  pinMode(PIN_JS1X, INPUT);
  pinMode(PIN_JS1Y, INPUT);
  pinMode(PIN_FLAPS, INPUT);

  // Set up LED pins
  pinMode(PIN_LOC, OUTPUT);
  pinMode(PIN_ATHR, OUTPUT);
  pinMode(PIN_AP1, OUTPUT);
  pinMode(PIN_AP2, OUTPUT);
  pinMode(PIN_EXPED, OUTPUT);
  pinMode(PIN_APPR, OUTPUT);
  pinMode(PIN_VIEW, OUTPUT);
  pinMode(PIN_WARN, OUTPUT);
  pinMode(PIN_CAUT, OUTPUT);

  // Set up SPEAKER pin
  pinMode(PIN_SPEAKER, OUTPUT);

  // Lamp test on
  Serial.printf("Lamp test on. (%d)\n", millis());
  digitalWrite(PIN_LOC, HIGH);
  digitalWrite(PIN_ATHR, HIGH);
  digitalWrite(PIN_AP1, HIGH);
  digitalWrite(PIN_AP2, HIGH);
  digitalWrite(PIN_EXPED, HIGH);
  digitalWrite(PIN_APPR, HIGH);
  digitalWrite(PIN_VIEW, HIGH);
  digitalWrite(PIN_WARN, HIGH);
  digitalWrite(PIN_CAUT, HIGH);

  // USB gamepad initialization
  Serial.printf("Initializing USB. (%d)\n", millis());
  gp.begin();
  USB.begin();

  // Initialize for I2C
  Serial.printf("Initializing I2C. (%d)\n", millis());
  Wire.begin(SCREEN_SDA, SCREEN_SCL);

  // Initialize FDU encoder settings
  Serial.printf("Initializing encoders. (%d)\n", millis());
  encoderSPD.setPosition(encoderSPDPos);
  encoderHDG.setPosition(encoderHDGPos);
  encoderALT.setPosition(encoderALTPos);
  encoderVS.setPosition(encoderVSPos);

  // Force display refresh on first loop
  encoderSPDPos = dontSendSPD;
  encoderHDGPos = dontSendHDG;
  encoderALTPos = dontSendALT;
  encoderVSPos = dontSendVS;

  // Initialize OLED I2C and all pixels on test
  Serial.printf("Initializing OLED displays. (%d)\n", millis());
  for (uint8_t s = 0; s < 5; s++) {
    selectOLED(s);
    display.begin(SSD1306_SWITCHCAPVCC, SCREEN_ADDR);  // initialize OLED I2C
    display.clearDisplay();
    display.fillRect(0, 0, SCREEN_WIDTH, SCREEN_HEIGHT, WHITE);
    display.display();
  }

  // Wake up beep
  Serial.printf("Wake up beep. (%d)\n", millis());
  tone(PIN_SPEAKER, 2000, 100);

  // Lamp test off
  delay(1500);
  digitalWrite(PIN_LOC, LOW);
  digitalWrite(PIN_ATHR, LOW);
  digitalWrite(PIN_AP1, LOW);
  digitalWrite(PIN_AP2, LOW);
  digitalWrite(PIN_EXPED, LOW);
  digitalWrite(PIN_APPR, LOW);
  digitalWrite(PIN_VIEW, LOW);
  digitalWrite(PIN_CAUT, LOW);
  digitalWrite(PIN_WARN, LOW);

  // OLED pixel test off
  for (uint8_t s = 0; s < 5; s++) {
    selectOLED(s);
    display.clearDisplay();
    display.display();
  }

  // Block waiting for gear lever down
  Serial.printf("Checking for gear lever down. (%d)\n", millis());
  while (digitalRead(PIN_GEAR)) {
    // Display message to user
    selectOLED(0);
    display.clearDisplay();
    display.setTextSize(2);
    display.setTextColor(WHITE);
    display.setCursor(0, 0);
    display.printf("Move gear\nlever --->\n");
    display.display();
    digitalWrite(PIN_WARN, HIGH);
    delay(250);

    // Blink message while waiting
    display.clearDisplay();
    display.display();
    digitalWrite(PIN_WARN, LOW);
    delay(250);
  }

  Serial.printf("Setup done; starting main loop. (%d)\n", millis());
}

// Check for reboot/debug commands
void handleSystemInputs() {
  // Long press EXPED to reboot
  if (oldRL2 == 7 && whenRL2 == -1 && currentTime - lastAct > 2000) {
    ESP.restart();
  }

  // Long press LOC to toggle debug output
  if (oldRL2 == 2 && whenRL2 == -1 && currentTime - lastAct > 2000) {
    lastAct = currentTime;
    debugMode = ! debugMode;
  }
}

// Do stateful switches and master warning blink
void handleSwitchesAndLEDs() {
  // Throttled to once per 300 loops
  if (loopCount % 300 == 0) {
    // Get stateful button values
    int newGear = digitalRead(PIN_GEAR);
    int newUnits = digitalRead(PIN_UNITS);

    // Handle gear event
    if (oldGear != newGear) {
      lastAct = currentTime;

      if (newGear) {
        Serial.printf("controls.gearDown(-1);\n");
        if (oldGear != -1) tone(PIN_SPEAKER, 54, 85);
      } else {
        Serial.printf("controls.gearDown(1);\n");
        if (oldGear != -1) tone(PIN_SPEAKER, 42, 85);
      }
      oldGear = newGear;
    }

    // Handle units event
    if (oldUnits != newUnits) {
      lastAct = currentTime;

      if (newUnits) {
        Serial.printf("setprop('it-autoflight/config/altitude-dial-mode', 0);\n");
        if (oldUnits != -1) tone(PIN_SPEAKER, 1500, 8);
      } else {
        Serial.printf("setprop('it-autoflight/config/altitude-dial-mode', 1);\n");
        if (oldUnits != -1) tone(PIN_SPEAKER, 1650, 8);
      }

      unitsMode = newUnits;
      oldUnits = newUnits;
    }

    // Blink master warning LED at 2 Hz
    if (warnBlink && currentTime % 500 > 250) {
      digitalWrite(PIN_WARN, HIGH);
    } else {
      digitalWrite(PIN_WARN, LOW);
    }
  }
}

// Read analog axis and flaps values
void handleAnalogControls() {
  // Throttled by potMillis
  if (currentTime - whenPot > potMillis) {
    // Read joysticks and send axis events
    if (viewMode) {
      // Apply rolling average damping for smooth view panning
      int rawX = scaleAxis(PIN_JS0X);
      int rawY = scaleAxis(PIN_JS0Y);
      int smoothX = smoothViewAxis(viewAxisXBuffer, rawX, &smoothedViewX);
      int smoothY = smoothViewAxis(viewAxisYBuffer, rawY, &smoothedViewY);
      gp.leftTrigger(smoothX);
      gp.rightTrigger(smoothY);

      // Increment buffer index for both axes
      viewBufferIndex = (viewBufferIndex + 1) % VIEW_AVG_WINDOW;
    } else {
      gp.leftStick(scaleAxis(PIN_JS0X), scaleAxis(PIN_JS0Y));
    }
    gp.rightStick(scaleAxis(PIN_JS1X), scaleAxis(PIN_JS1Y));

    // Read flaps potentiometer
    int newFlapsPos = getFlapsPos(PIN_FLAPS);

    // Handle flaps change
    if (oldFlapsPos != newFlapsPos) {
      lastAct = currentTime;

      // Send nasal command
      Serial.printf("pts.Controls.Flight.flaps.setValue(%.1f);\n", 0.2 * newFlapsPos);

      // Flaps sound
      if (oldFlapsPos != -1) {
        if (newFlapsPos > oldFlapsPos) {
          tone(PIN_SPEAKER, 1200, 8);
        } else {
          tone(PIN_SPEAKER, 1100, 8);
        }
      }
      
      oldFlapsPos = newFlapsPos;
    }

    whenPot = currentTime;
  }
}

// Process button press events
void handleResistorLadders() {
  // Throttled to once per 8 loops
  if (loopCount % 8 == 0) {
    int newRL1 = getButton(PIN_RL1);
    int newRL2 = getButton(PIN_RL2);
    int newRL3 = getButton(PIN_RL3);

    // Detect change and set bounce timers
    if (oldRL1 != newRL1) { whenRL1 = currentTime + bounceWait; oldRL1 = newRL1; }
    if (oldRL2 != newRL2) { whenRL2 = currentTime + bounceWait; oldRL2 = newRL2; }
    if (oldRL3 != newRL3) { whenRL3 = currentTime + bounceWait; oldRL3 = newRL3; }

    // Process RL1 buttons
    if (whenRL1 < currentTime) {
      lastAct = currentTime;
      
      // Send button event
      if (newRL1 > 0) {
        (buttonMap[newRL1 - 1] >= 0) && gp.pressButton(buttonMap[newRL1 - 1]);
        boop();
      } else {
        (buttonMap[prevRL1 - 1] >= 0) && gp.releaseButton(buttonMap[prevRL1 - 1]);
      }

      // Remember for button release
      prevRL1 = newRL1;

      // Reset timer
      whenRL1 = -1;
    }

    // Process RL2 buttons
    if (whenRL2 < currentTime) {
      lastAct = currentTime;

      // Send button event
      if (newRL2 > 0) {
        (buttonMap[newRL2 + 7] >= 0) && gp.pressButton(buttonMap[newRL2 + 7]);
        boop();
      } else {
        (buttonMap[prevRL2 + 7] >= 0) && gp.releaseButton(buttonMap[prevRL2 + 7]);
      }

      // Handle speed mode change
      if (newRL2 == 3) {
        ktsMachMode = ! ktsMachMode;
        encoderSPDPos = dontSendSPD;
        encoderSPD.setPosition(100);
      }

      // Handle TRK/FPA mode change
      if (newRL2 == 6) {
        trkFpaMode = ! trkFpaMode;
        encoderHDGPos = dontSendHDG;
        encoderVSPos = dontSendVS;
        vsDashes = true;
      }

      // Remember for button release
      prevRL2 = newRL2;

      // Reset timer
      whenRL2 = -1;
    }

    // Process RL3 buttons
    if (whenRL3 < currentTime) {
      lastAct = currentTime;

      // Send button event
      if (newRL3 > 0) {
        (buttonMap[newRL3 + 15] >= 0) && gp.pressButton(buttonMap[newRL3 + 15]);
        boop();
      } else {
        (buttonMap[prevRL3 + 15] >= 0) && gp.releaseButton(buttonMap[prevRL3 + 15]);
      }

      // Handle view mode change
      if (newRL3 == 4) {
        if (currentTime - lastViewPress < 500) { // double press resets view
          // Send nasal command
          Serial.printf("view.setViewByIndex(0);view.resetViewDir();view.resetFOV();view.increase(20);\n");
        }
        viewMode = ! viewMode;
        digitalWrite(PIN_VIEW, viewMode);
        lastViewPress = currentTime;
      }

      // Handle cycle view button
      if (viewMode && newRL3 == 6) {
        // Send nasal command
        Serial.printf("view.stepView(1);\n");
      }

      // Remember for button release
      prevRL3 = newRL3;

      // Reset timer
      whenRL3 = -1;
    }
  }
}
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
void loop() {
  // Used for throttling logic
  loopCount++;
  currentTime = millis();

  // Check for reboot/debug commands
  handleSystemInputs();

  // Do stateful switches and master warning blink
  handleSwitchesAndLEDs();

  // Read analog axis and flaps values
  handleAnalogControls();

  // Process button press events
  handleResistorLadders();

  // Tick rotary encoders
  handleEncoders();

  // Process incoming data from FlightGear
  handleSerialInput();

  // Low priority display tasks
  handlePeriodicUpdates();
}

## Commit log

2026-02-13 parts for 3d printing
    [alt-units-knob-flange.scad, alt-units-knob-pointer.scad, alt-units-knob-ring.scad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]
2026-02-13 artwork for labels and buttons
2026-02-13 firmware for ESP32
2026-02-19 use nasal for stateful switches
2026-03-10 new fuselage image
2026-03-10 fix spelling
    [fcu-p1-ins.scad, flaps-control-mockup.scad, js-dome.scad]
2026-03-17 fix SPD display props
2026-03-30 update for detent encoders
2026-04-11 fix encoder acceleration
